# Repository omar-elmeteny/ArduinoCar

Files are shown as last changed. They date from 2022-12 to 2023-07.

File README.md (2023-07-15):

# CSEN701: EMBEDDED SYSTEM ARCHITECTURE

## Arduino controlled car

An arduino  controlled car with the following features:
- MP3 player controlled by LCD-TFT touch screen.
- Remote control using bluetooth
- Gear displayed using 7-segment display.
- Adaptive Head Light display
- Parallel Parking
- Distance sensor with buzzer

## Team Members

|Name|ID|Tutorial|
|---|---|---|
|Omar Sherif El-Meteny|49-3317|T17|
|Ziad Tamer|49-1866|T9|
|Amr Mohamed Samy|49-6656|T17|
|Rana Wally|49-0534|T17|
|Abdelrahman Mohamed Mahmoud Aboelmaaty Abdo|49-4016|T18|

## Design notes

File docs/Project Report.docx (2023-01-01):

# Project Report

CSEN701: Embedded System Architecture

Winter Semester 2022 Project

ARDUINO CONTROLLED CAR

## Team Members:

- Omar Sherif El-Meteny/49-3317/T17
- Ziad Tamer/49-1866/T9
- Amr Mohamed Samy/49-6656/T17
- Rana Wally/49-0534/T17
- Abdelrahman Mohamed Mahmoud Aboelmaaty Abdo/49-4016/T18

## Project Description:

In this project, some of the common car features were implemented using Arduino Mega and Arduino Uno boards and FreeRTOS library. These features are autonomous car-maneuvering system that performs parallel parking using sensors, displaying the car’s current gear on a 7-Segment display, using adaptive Headlights to adapt the car’s headlights according to the surrounding light intensity, and finally playing MP3 files via a speaker on the car and system should be controlled using LCD-TFT touch screen. The project was divided into 2 sub-projects, one using Arduino Uno board and the other using Arduino Mega. The Arduino Uno board was used for the car and the Arduino Mega was used for the controlling the car. Bluetooth modules were used as a communication port between the two Arduino boards.

## Components:

1. Arduino Uno Board (used to supply power components on the breadboard and implement functionalities related to the car).
2. Arduino Mega Board (used to supply power for the components that are responsible for controlling the car and other components and implement their functionalities).
3. H-Bridge (used to control the car’s motors by sending the correct signal for each motor according to the functionality needed).
4. 4X Ultrasonic sensors (used to detect the distance between the car and the surrounding obstacles).
5. 2X HC-05 (used as a communication port between the 2 Arduino Boards).
6. 2X Breadboards (used to place the components on them and supply power and signals for all components).
7. Joystick module (used to control the car’s current gear and the car’s movement).
8. MP3 module (used to play MP3 files downloaded on SD-Card).
9. LDR sensor (used to detect light intensity surrounding the car).
10. 0.25W-32Ohm Speaker (used for listening to the songs played by the MP3 module).
11. 1 Transparent LED (used as an Adaptive Headlight according to the surrounding light intensity).
12. 7-Segment display (used to display the car’s current gear).
13. LCD-TFT (used to play/pause the song, get the next or previous songs, and finally displays the name of the current song).
14. Several 1KOhm resistors (used for LEDs and 7-Segment and Bluetooth modules).
15. 9V batteries (used to supply extra power for the Arduino Boards).
16. Buzzer (used as an audible warning and its tone changes according to the distance between the car and the surrounding obstacles).
17. Jumper wires (used for pin assignments).
18. RC-Car (used to simulate the project).

## Project Circuits:

### Car Sketch:

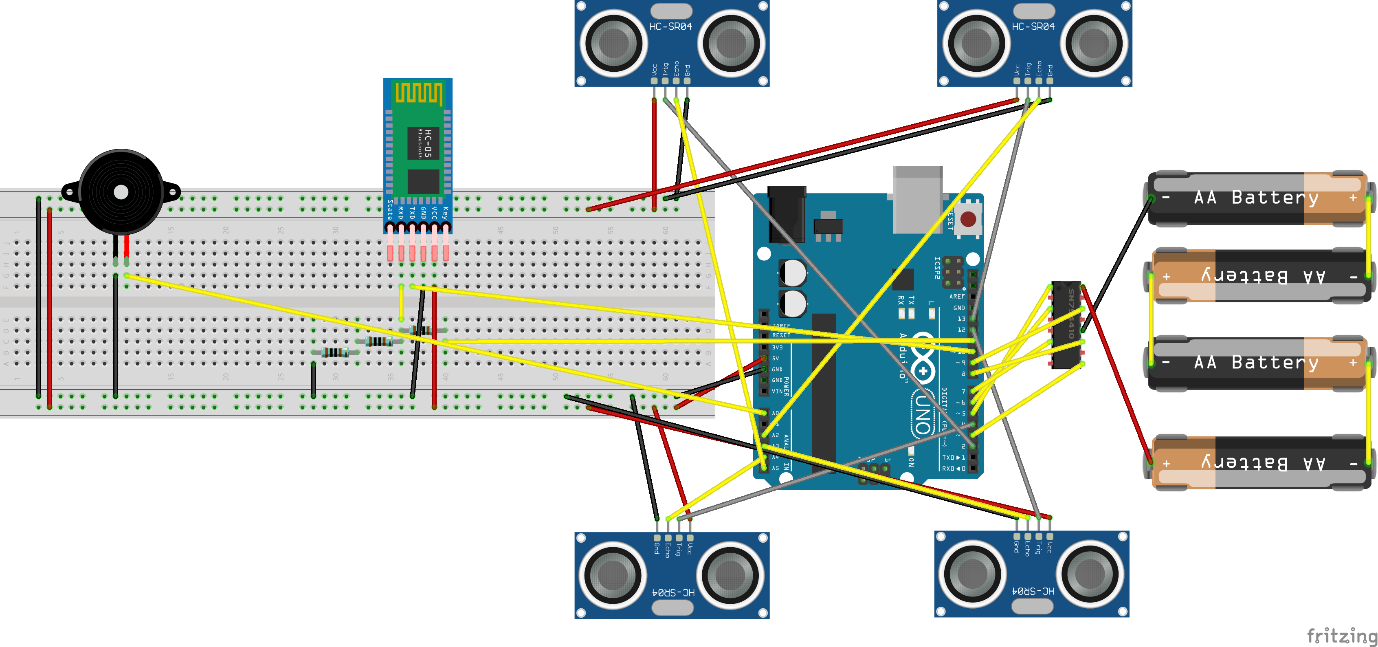
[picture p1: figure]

### Car Remote Sketch:

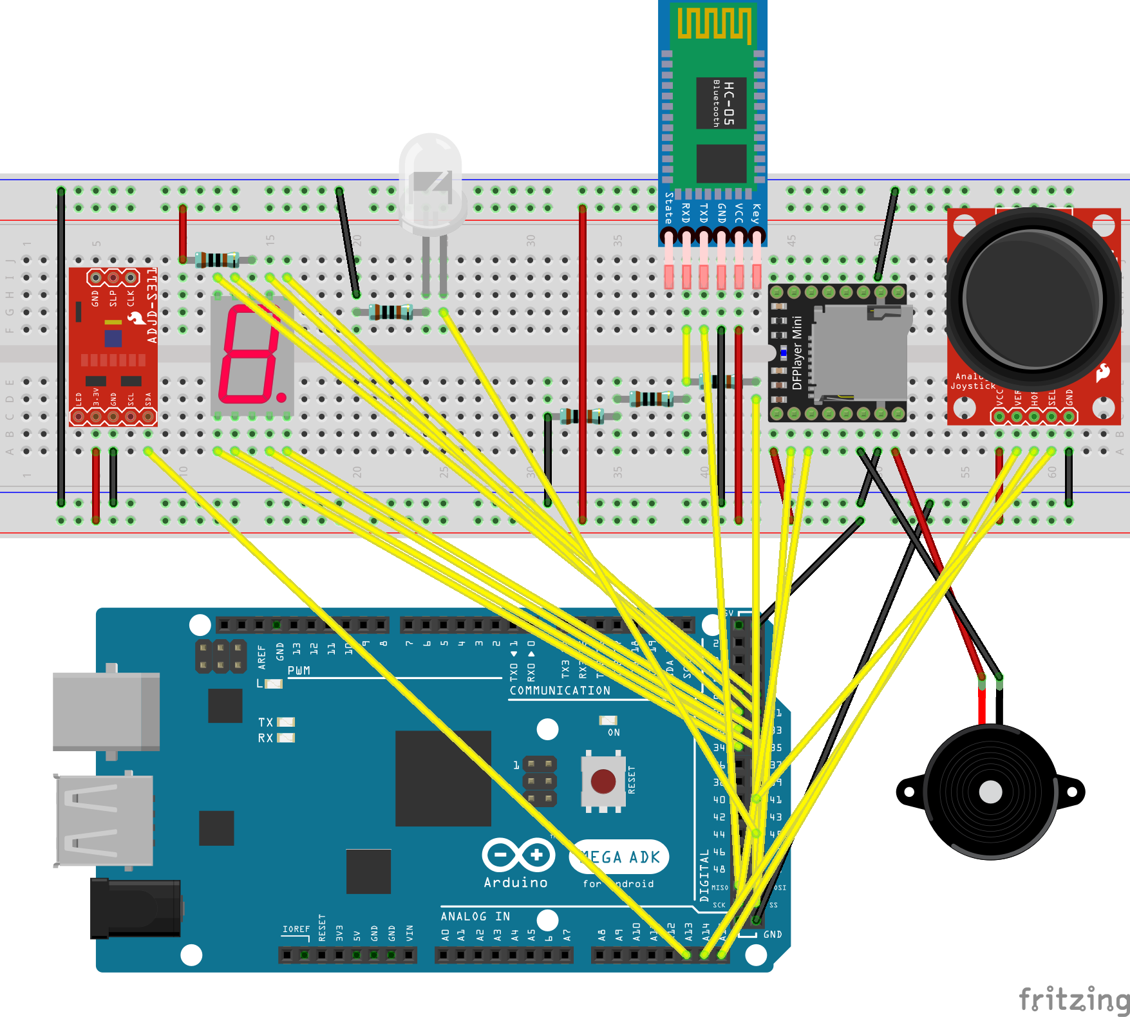
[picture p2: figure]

## Project Libraries:

1. SoftwareSerial (used to establish serial communication between the Arduinos and the Bluetooth modules and to send commands from the Arduino Mega to the MP3 Player module).
2. Arduino_FreeRTOS (used to create tasks for the different features and scheduling those tasks).
3. DFRobotDFPlayerMini (used to control the MP3 Player module).
4. MCUFRIEND_kbv (used to draw shapes and write text on the LCD-TFT screen).
5. Adafruit_GFX (this is a dependency needed by MCUFRIEND_kbv library).
6. TouchScreen (used to handle touch screen inputs).

## Inputs:

Inputs were taken from the components and assigned to digital or analog input pins of the Arduino Board. This was done by defining new variables and assigning the pins to those variables and those variables were set to inputs in the setup function. Handling those inputs was done by if-else statements and according to the values a certain output was returned.

## Outputs:

Outputs were produced by the Arduino and were taken from digital output pins or PWM pins. This was done by defining new variables and assigning the pins to those variables and those variables were set to outputs in the setup function. Handling outputs was done in the FreeRTOS tasks and changed according to the inputs produced by the different components. The outputs were changed by setting the variables as HIGH or LOW if the output was digital or assigning values to the variables from 0 to 255 if PWM was used.

## FreeRTOS:

### Car Remote Tasks:

1. Input Task (used to handle inputs produced from Joystick, Touch Screen and Bluetooth).
2. 7-Segment Task (used to display the change in the car’s current gear).
3. MP3 Player Task (used to switch between the songs played by the MP3 Player according to touch screen inputs).
4. Touch Screen Task (used to update the screen according to current song).

The Input Task has the lowest priority because the rest of the tasks are sleeping most of the time waiting for their inputs. The other tasks have higher priority than that of the Input Task because they must execute once they are notified that an input is produced before processing more inputs. The Touch Screen Task has a priority lower than the 7-Segment and the MP3 Player Tasks because it takes more time in execution.

### Car Tasks:

1. Buzzer Task (used to produce tones and changes according to the distance between the car and the surrounding obstacles).
2. Sensor Task (used to detect distances between the car and the surrounding obstacles).
3. Car Control Task (used to control the car according to the car’s current gear with different speeds (PWM)).
4. Bluetooth Task (used to receive inputs from the Arduino Mega Board and handles those inputs. Moreover, it is used for autonomous parallel parking).

The Bluetooth task has the lowest priority because the rest of the task are sleeping most of the time waiting for their inputs. The other task have higher priority than that of Bluetooth Task because they must execute once they are notified that an input is produced before processing more inputs. The Sensor Task has a priority lower than the Car Control and Buzzer Task because it is considered an input to the Buzzer Task.

## Project Problems and Limitations:

The first problem encountered in this project was the code implementation of the LCD-TFT and the Joystick because they were implemented in separate tasks. The problem was that both modules were connected to analog input pins and the Arduino was trying to read the analog values produced by both modules at the same time and this caused problems in the readings. This problem was solved by using a mutex for analog reading so that the Arduino cannot read analog inputs from both modules at the same time. Unfortunately, this approach caused another problem which was in responsiveness. The tasks that take the produced inputs didn’t respond with proper timing. At the end, both tasks were implemented in a single task which is the Input Task mentioned above and any other task that was used to read inputs was implemented in that same task (Input Task).

The second problem was in the two libraries used for the implementation of LCD-TFT functionality. MCUFRIEND_kbv library was responsible for reading inputs from specific pins and TouchScreen library was responsible for producing the outputs using the same pins so there was a race condition between the two operations. To solve this problem, a Mutex was used to prevent these 2 operations from executing at the same time.

Another limitation was that, in the library responsible for MP3 functionality, there were no APIs to get the name of the current song, so the song names had to be hardcoded to show them on the LCD-TFT screen.

## Team Contribution:

First of all, it was a collaborative team effort since all of us worked together to implement the project code and hardware. To be more specific, each one of us was responsible of a specific part.

1. Omar Sherif El-Meteny (implemented car remote code and Bluetooth communication).
2. Ziad Tamer (made car remote circuit).
3. Amr Mohamed Samy (assembled the car a connected the sensors and buzzer to the car).
4. Rana Wally (implemented sensor and buzzer code and car movement code).
5. Abdelrahman Mohamed Mahmoud Aboelmaaty Abdo (implemented autonomous parking code).

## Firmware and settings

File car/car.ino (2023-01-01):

#include <SoftwareSerial.h>
#include <Arduino_FreeRTOS.h>
#include <math.h>
#include <float.h>
#include <limits.h>

#include "common.h"

#include "car.h"
#include "distanceSensor.h"
#include "buzzer.h"

SoftwareSerial BTSerial(10, 11);

void bluetoothReceiveTask(void *pvParameters);
void carControlTask(void *pvParameters);
void sensorTask(void *pvParameters);
void buzzerTask(void *pvParameters);
void parkingTask(void *pvParameters);

TaskHandle_t carControlTaskHandle;
TaskHandle_t buzzerTaskHandle;
void setup() {
#ifdef DEBUG
  Serial.begin(38400);
#endif

  setupCar();
  setupBuzzer();
  setupDistanceSensors();
  BTSerial.begin(38400);
  BTSerial.listen();

  xTaskCreate(buzzerTask, "BUZ", 128, NULL, 5, &buzzerTaskHandle);
  xTaskCreate(sensorTask, "SENSOR", 128, NULL, 2, NULL);
  xTaskCreate(carControlTask, "CAR", 128, NULL, 5, &carControlTaskHandle);

  xTaskCreate(bluetoothReceiveTask, "BT_RCV", 128, NULL, 1, NULL);
}

void waitUntilObstacleOrTime(uint32_t ms, bool front, float distance) {
  TickType_t entryTime = xTaskGetTickCount();
  TickType_t exitTime = entryTime + pdMS_TO_TICKS(ms);
  uint8_t leftSensor = front ? FRONT_LEFT : BACK_LEFT;
  uint8_t rightSensor = front ? FRONT_RIGHT : BACK_RIGHT;


  while (readDistanceCentimeters(leftSensor) > distance && readDistanceCentimeters(rightSensor) > distance
         && xTaskGetTickCount() < exitTime) {
  }
}

void stopCar() {
#ifdef DEBUG
  Serial.println("Stopping car");
#endif

  xTaskNotify(carControlTaskHandle, 'n', eSetValueWithoutOverwrite);
  xTaskNotify(carControlTaskHandle, 's', eSetValueWithoutOverwrite);

#ifdef DEBUG
  vTaskDelay(pdMS_TO_TICKS(5000));
#else
  vTaskDelay(pdMS_TO_TICKS(500));
#endif
}

void reverseCar(uint32_t ms, bool checkSensor) {
#ifdef DEBUG
  Serial.println("Reversing car");
#endif

  xTaskNotify(carControlTaskHandle, 's', eSetValueWithoutOverwrite);
  xTaskNotify(carControlTaskHandle, 'r', eSetValueWithoutOverwrite);

  if (checkSensor) {
    waitUntilObstacleOrTime(ms, false, 5);
  } else {
    vTaskDelay(pdMS_TO_TICKS(ms));
  }

  stopCar();
}

void rotateCar(bool reverse, bool rightSide) {
#ifdef DEBUG
  Serial.println("Rotating car");
#endif
  xTaskNotify(carControlTaskHandle, rightSide ? 'a' : 'd', eSetValueWithoutOverwrite);
  xTaskNotify(carControlTaskHandle, reverse ? 'r' : '3', eSetValueWithoutOverwrite);
  waitUntilObstacleOrTime(1500, !reverse, 5);

  stopCar();
}

void parkCar(bool rightSide) {
#ifdef DEBUG
  Serial.println(rightSide ? "Parking right side" : "Parking left side");
#endif

  reverseCar(500, false);
  rotateCar(true, rightSide);
  reverseCar(1000, false);
  rotateCar(false, rightSide);

#ifdef DEBUG
  Serial.println("Car parked");
#endif
}

void buzzerTask(void *pvParamters) {
  uint32_t distance = DISTANCE_FAR;
  bool isBuzzing = false;
  while (true) {
    TickType_t delayTicks = distance == DISTANCE_FAR      ? portMAX_DELAY
                            : distance == DISTANCE_MEDIUM ? pdMS_TO_TICKS(DELAY_MEDIUM)
                            : distance == DISTANCE_CLOSE  ? pdMS_TO_TICKS(DELAY_CLOSE)
                                                          : pdMS_TO_TICKS(DELAY_VERY_CLOSE);
    uint32_t distanceNotification;
    if (xTaskNotifyWait(ULONG_MAX, ULONG_MAX, &distanceNotification, delayTicks) && distanceNotification) {
      distance = distanceNotification;
    }
    if (distance == DISTANCE_FAR && isBuzzing) {
      noTone(BUZZER_PIN);
    } else if (distance != DISTANCE_FAR) {
      if (isBuzzing) {
        noTone(BUZZER_PIN);
      } else {
        tone(BUZZER_PIN, BUZZER_FREQUENCY);
      }
      isBuzzing = !isBuzzing;
    }
  }
}

void sensorTask(void *pvParameters) {
  float distancesCentimeters[SENSOR_COUNT];
  for (int i = 0; i < SENSOR_COUNT; i++) {
    distancesCentimeters[i] = -1;
  }
  uint32_t minDistance = DISTANCE_FAR;
  while (true) {
    vTaskDelay(pdMS_TO_TICKS(100));
    float minDistaneCm = FLT_MAX;
    for (uint8_t i = 0; i < SENSOR_COUNT; i++) {
      float oldDistanceCentimeters = distancesCentimeters[i];
      double newDistanceCentimeters = readDistanceCentimeters(i);
      // #if DEBUG
      // if (abs(newDistanceCentimeters - oldDistanceCentimeters) > DISTANCE_EPSILON_CM) {
      //   Serial.print("distance change sensor");
      //   Serial.print(i == 0 ? " FL " : i == 1 ? " FR "
      //                                : i == 2 ? " BL "
      //                                         : " BR ");
      //   Serial.println(newDistanceCentimeters);
      //   distancesCentimeters[i] = newDistanceCentimeters;
      // }
      // #endif
      if (newDistanceCentimeters < minDistaneCm) {
        minDistaneCm = newDistanceCentimeters;
      }
    }

    uint32_t newDistance = minDistaneCm > DISTANCE_MEDIUM_CM       ? DISTANCE_FAR
                           : minDistaneCm > DISTANCE_CLOSE_CM      ? DISTANCE_MEDIUM
                           : minDistaneCm > DISTANCE_VERY_CLOSE_CM ? DISTANCE_CLOSE
                                                                   : DISTANCE_VERY_CLOSE;

    if (newDistance != minDistance) {
      xTaskNotify(buzzerTaskHandle, (uint32_t)newDistance, eSetValueWithOverwrite);
      minDistance = newDistance;
    }
  }
}

void bluetoothReceiveTask(void *pvParamters) {
#if DEBUG
  Serial.println("Starting bluetooth receive.");
#endif

  while (true) {
    if (BTSerial.available()) {
      char c = BTSerial.read();
      switch (c) {
        case 'r':
        case 'n':
        case '1':
        case '2':
        case '3':
        case 'a':
        case 's':
        case 'd':
          xTaskNotify(carControlTaskHandle, (uint32_t)c, eSetValueWithOverwrite);
#if DEBUG
          Serial.print("Received car control: ");
          Serial.println(c);
#endif
          break;
        case 'p':
          parkCar(true);
          break;
      }
    }
  }
}

void carControlTask(void *pvParameters) {
#if DEBUG
  Serial.println("Starting car control task.");
#endif
  uint32_t carCommand;
  int8_t motorValue = 0;
  int8_t direction = 0;

  while (true) {
    if (xTaskNotifyWait(ULONG_MAX, ULONG_MAX, &carCommand, portMAX_DELAY) && carCommand) {
      char cmd = (char)carCommand;
      switch (cmd) {
        case 'r':
          motorValue = -1;
          break;
        case 'n':
        case 'p':
          motorValue = 0;
          break;
        case '1':
        case '2':
        case '3':
          motorValue = cmd - '0';
          break;
        case 's':
          direction = 0;
          break;
        case 'a':
          direction = -1;
          break;
        case 'd':
          direction = 1;
          break;
      }
      // #ifdef DEBUG
      //       Serial.print("Direction = ");
      //       Serial.print(direction);
      //       Serial.print(", MotorValue = ");
      //       Serial.println(motorValue);
      // #endif
      if (direction == 0) {
        setCarMovement(motorValue, motorValue);
      } else if (direction == 1) {
        setCarMovement(0, motorValue);
      } else {
        setCarMovement(motorValue, 0);
      }
    }
  }
}

void loop() {
}

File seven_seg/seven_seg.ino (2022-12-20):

/*
  Showing numbers, chars and phrases
                             A (seg[0] in this project)
                            ---
F (seg[5] in this project) |   | B (seg[1] in this project)
                           |   | 
                            --- G (seg[6] in this project)
E (seg[4] in this project) |   | 
                           |   | C (seg[2] in this project)
                            ---  . dot or dicimal (seg[7] in this project)
                             D (seg[3] in this project)

 */
#define A 8
#define B 9
#define C 6
#define D 5
#define E 4
#define F 3
#define G 2
#define DP 7  // decimal
#define common_cathode 0
#define common_anode 1
bool segMode = common_anode;         // set this to your segment type, my segment is common_cathode
int seg[]{ A, B, C, D, E, F, G, DP };  // segment pins
byte chars = 35;                       // max value in the array "Chars"

byte Chars[35][9]{
  { '0', 1, 1, 1, 1, 1, 1, 0, 0 },  //0
  { '1', 0, 1, 1, 0, 0, 0, 0, 0 },  //1
  { '2', 1, 1, 0, 1, 1, 0, 1, 0 },  //2
  { '3', 1, 1, 1, 1, 0, 0, 1, 0 },  //3
  { '4', 0, 1, 1, 0, 0, 1, 1, 0 },  //4
  { '5', 1, 0, 1, 1, 0, 1, 1, 0 },  //5
  { '6', 1, 0, 1, 1, 1, 1, 1, 0 },  //6
  { '7', 1, 1, 1, 0, 0, 0, 0, 0 },  //7
  { '8', 1, 1, 1, 1, 1, 1, 1, 0 },  //8
  { '9', 1, 1, 1, 1, 0, 1, 1, 0 },  //9
  { 'a', 1, 1, 1, 0, 1, 1, 1, 0 },  //A/10
  { 'b', 0, 0, 1, 1, 1, 1, 1, 0 },  //b/11
  { 'c', 1, 0, 0, 1, 1, 1, 0, 0 },  //C/12
  { 'd', 0, 1, 1, 1, 1, 0, 1, 0 },  //d/13
  { 'e', 1, 0, 0, 1, 1, 1, 1, 0 },  //E/14
  { 'f', 1, 0, 0, 0, 1, 1, 1, 0 },  //F/15
  { 'g', 1, 0, 1, 1, 1, 1, 0, 0 },  //G/16
  { 'h', 0, 1, 1, 0, 1, 1, 1, 0 },  //H/17
  { 'i', 0, 0, 0, 0, 1, 1, 0, 0 },  //I/18
  { 'j', 0, 1, 1, 1, 1, 0, 0, 0 },  //J/19
  { 'l', 0, 0, 0, 1, 1, 1, 0, 0 },  //L/20
  { 'n', 0, 0, 1, 0, 1, 0, 1, 0 },  //n/21
  { 'o', 0, 0, 1, 1, 1, 0, 1, 0 },  //o/22
  { 'p', 1, 1, 0, 0, 1, 1, 1, 0 },  //P/23
  { 'q', 1, 1, 1, 0, 0, 1, 1, 0 },  //q/24
  { 'r', 0, 0, 0, 0, 1, 0, 1, 0 },  //r/25
  { 's', 1, 0, 1, 1, 0, 1, 1, 0 },  //S/26   looks like number 5
  { 't', 0, 0, 0, 1, 1, 1, 1, 0 },  //t/27
  { 'u', 0, 1, 1, 1, 1, 1, 0, 0 },  //U/28
  { 'y', 0, 1, 1, 1, 0, 1, 1, 0 },  //y/29
  { '-', 0, 0, 0, 0, 0, 0, 1, 0 },  //-/30
  { '.', 0, 0, 0, 0, 0, 0, 0, 1 },  //./31
  { ']', 1, 1, 1, 1, 0, 0, 0, 0 },  //]/32
  { '[', 1, 0, 0, 1, 1, 1, 0, 0 },  //[/33
  { '_', 0, 0, 0, 1, 0, 0, 0, 0 },  //_/34
};

void setup() {
  // set segment pins as OUTPUT
  pinMode(seg[0], OUTPUT);
  pinMode(seg[1], OUTPUT);
  pinMode(seg[2], OUTPUT);
  pinMode(seg[3], OUTPUT);
  pinMode(seg[4], OUTPUT);
  pinMode(seg[5], OUTPUT);
  pinMode(seg[6], OUTPUT);
  pinMode(seg[7], OUTPUT);
}



void setState(bool mode)  //sets the hole segment state to "mode"
{
  for (int i = 0; i <= 6; i++) {
    digitalWrite(seg[i], mode);
  }
}



void Print(char Char)  // print any character on the segment ( Note : you can't use capital characters )
{
  int charNum = -1;   // set search resault to -1
  setState(segMode);  //turn off the segment

  for (int i = 0; i < chars; i++) {  //search for the enterd character
    if (Char == Chars[i][0]) {       //if the character found
      charNum = i;                   //set the resault number into charNum ( because this function prints the character using it's number in the array )
    }
  }

  if (charNum == -1)  // if the character not found
  {
    for (int i = 0; i <= 6; i++) {
      digitalWrite(seg[i], HIGH);
      delay(100);
      digitalWrite(seg[i], LOW);
    }
    for (int i = 0; i <= 2; i++) {
      delay(100);
      setState(HIGH);
      delay(100);
      setState(LOW);
    }
  } else  // else if the character found print it
  {
    for (int i = 0; i < 8; i++) {
      digitalWrite(seg[i], Chars[charNum][i + 1]);
    }
  }
}

void Print(int num)  // print any number on the segment
{
  setState(segMode);  //turn off the segment



  if (num > chars || num < 0)  // if the number is not declared
  {
    for (int i = 0; i <= 6; i++) {
      digitalWrite(seg[i], HIGH);
      delay(100);
      digitalWrite(seg[i], LOW);
    }
    for (int i = 0; i <= 2; i++) {
      delay(100);
      setState(HIGH);
      delay(100);
      setState(LOW);
    }
  } else  // else if the number declared, print it
  {
    if (segMode == 0) {  //for segment mode
      for (int i = 0; i < 8; i++) {
        digitalWrite(seg[i], Chars[num][i + 1]);
      }
    } else {
      for (int i = 0; i < 8; i++) {
        digitalWrite(seg[i], !Chars[num][i + 1]);
      }
    }
  }
}

void loop() {


  for (int i = 0; i < chars; i++)  //print
  {
    Print(i);
    delay(3000);
  }


  //Print(number or character); // print any number or character on the segment ( Note : you can't use capital characters )
  //setState(state); //sets the hole segment state to "state"
}

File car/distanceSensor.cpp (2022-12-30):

#include <Arduino.h>
#include <stdint.h>
#include <Arduino_FreeRTOS.h>

#include "common.h"
#include "distanceSensor.h"

#define FRONT_LEFT_TRIG 4
#define FRONT_RIGHT_TRIG 12
#define BACK_LEFT_TRIG 2
#define BACK_RIGHT_TRIG 13

#define FRONT_LEFT_ECHO A4
#define FRONT_RIGHT_ECHO A3
#define BACK_LEFT_ECHO A5
#define BACK_RIGHT_ECHO A2

void setupDistanceSensors() {
  pinMode(FRONT_LEFT_TRIG, OUTPUT);
  pinMode(FRONT_LEFT_ECHO, INPUT);

  pinMode(FRONT_RIGHT_TRIG, OUTPUT);
  pinMode(FRONT_RIGHT_ECHO, INPUT);

  pinMode(BACK_LEFT_TRIG, OUTPUT);
  pinMode(BACK_LEFT_ECHO, INPUT);

  pinMode(BACK_RIGHT_TRIG, OUTPUT);
  pinMode(BACK_RIGHT_ECHO, INPUT);
}

void taskDelayMicroSeconds(uint32_t microSeconds) {
   vTaskDelay(pdMS_TO_TICKS(microSeconds) / 1000);
}

float readDistanceCentimeters(uint8_t sensor) {
  int trigPin;
  int echoPin;

  switch (sensor) {
    case FRONT_LEFT:
      trigPin = FRONT_LEFT_TRIG;
      echoPin = FRONT_LEFT_ECHO;
      break;
    case FRONT_RIGHT:
      trigPin = FRONT_RIGHT_TRIG;
      echoPin = FRONT_RIGHT_ECHO;
      break;
    case BACK_LEFT:
      trigPin = BACK_LEFT_TRIG;
      echoPin = BACK_LEFT_ECHO;
      break;
    case BACK_RIGHT:
      trigPin = BACK_RIGHT_TRIG;
      echoPin = BACK_RIGHT_ECHO;
      break;
    default: // We should never get here.
      return -1;
  }

  digitalWrite(trigPin, LOW);
  taskDelayMicroSeconds(2);
  //delayMicroseconds(2);
  digitalWrite(trigPin, HIGH);
  taskDelayMicroSeconds(10);
  //delayMicroseconds(10);
  digitalWrite(trigPin, LOW);
  float durationMicroseconds = pulseIn(echoPin, HIGH);
  return (float)durationMicroseconds * 0.0343f / 2;
}

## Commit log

2022-12-23 changed the joystick switch from pin 10 to 12
2022-12-27 Updated pin assignments for remote control
2022-12-27 fix bugs in car control code
    [car.cpp, car.ino]
2022-12-28 Add mp3 player code and draw the next, previous, play and pause buttons
2022-12-29 fixed issues with screen not updating for mp3 player
    [mp3Player.cpp, remote.ino]
2022-12-29 finished buzzer and distance sensor tasks
    [buzzer.h, car.ino, distanceSensor.cpp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]
2022-12-30 fixed issues with bluetooth
    [bluetooth_at.ino, remote.ino]
2022-12-30 finished light sensor
2022-12-30 added car remote sketch
    [Car_Remote_Sketch.fzz]
2022-12-31 fixed bugs with car direction control
    [car.cpp, car.ino]
2023-01-01 added sketches
    [Car_Remote_Sketch.fzz, Car_Sketch.fzz]
2023-01-01 Fixed issue with car parking code.
    [car.ino]
